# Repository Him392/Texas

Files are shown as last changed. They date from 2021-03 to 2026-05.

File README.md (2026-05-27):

# 德克萨斯 源石剑 自制道具

明日方舟「德克萨斯」源石剑的自制道具，包含 3D 打印手柄、亚克力剑身以及 ESP32 LED 控制固件。

Web BLE控制->https://him392.github.io/Texas/

视频链接：https://www.bilibili.com/video/BV1i34y1r77z

## 3D 预览

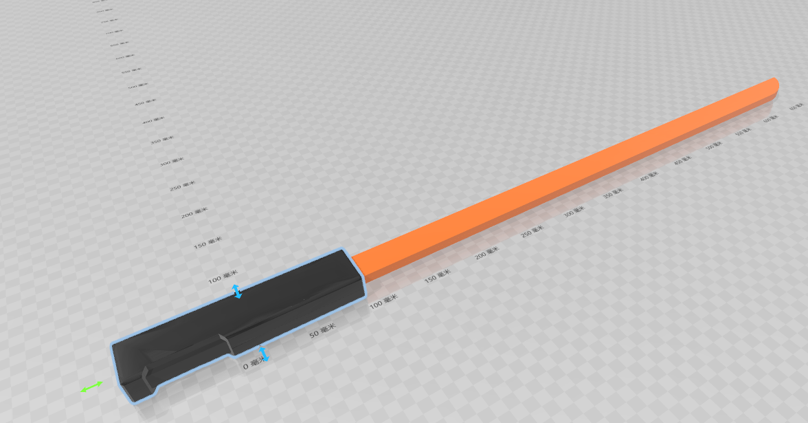
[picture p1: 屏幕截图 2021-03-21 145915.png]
预览图


## 文件说明

### 手柄部分（3D 打印）
| 文件 | 说明 |
|---|---|
| `Texas_1PCB.STL` / `.SLDPRT` | 手柄主体（装PCB的那面） |
| `Texas_2SW.STL` / `.SLDPRT` | 手柄主体（装开关的那面 |

### 剑身部分
| 文件 | 说明 |
|---|---|
| `Texas_A＆B_V2.DWG` | CAD 文件，用于淘宝定制亚克力板 |
| `Texas_A＆B_V2.SLDPRT` | SolidWorks 原始模型 |

### PCB
| 文件 | 说明 |
|---|---|
| `PCB(LCEDA).zip` | 立创 EDA PCB 工程文件 |

---

## 固件

固件基于 **ESP32-PICO** 平台（PlatformIO + Arduino 框架），LED 通过 LEDC PWM 驱动，提供两个版本：

### ESP32_AP — WiFi 热点控制版

- ESP32 开机后创建名为 **德克萨斯的源石剑-B** 的开放热点
- 手机/电脑连接热点后，访问 `192.168.4.1` 即可打开控制页面
- 控制功能：
  - **模式**：关闭 / 常亮 / 呼吸灯 / 闪烁
  - **亮度**调节滑块（常亮 / 闪烁模式下有效）
  - **实体按键**启用 / 禁用
  - 实时显示电池电压与 USB 充电状态
- 实体按键逻辑：
  - **短按**：关闭 ↔ 常亮 切换
  - **长按（250 ms）**：常亮 ↔ 呼吸灯 切换

### ESP32_BLE — 蓝牙 BLE 控制版

- 蓝牙广播名称：**Texas-Sword-B**
- 通过 BLE 特征值读写控制，断连后自动重新广播
- 支持通知推送：按键操作、USB 状态、电池电压实时同步给已连接设备
- BLE Service UUID：`4fafc201-1fb5-459e-8fcc-c5c9c331914b`
- 控制特征值：

| 功能 | UUID |
|---|---|
| 模式 | `beb5483e-36e1-4688-b7f5-ea07361b26a8` |
| 亮度 | `8c3bcf52-4752-46ac-a4de-a89e830e2f5f` |
| 实体按键 | `f0a3cc1e-eeed-426c-9a4f-ee72f778c1ee` |
| 电池电压 | `1de83dc6-3474-45e0-a2ef-cf4c01dcdc8c` |
| USB 状态 | `6bdab28d-19cd-488f-a42e-be255dfda983` |

### 引脚定义（两版通用）

| 信号 | GPIO |
|---|---|
| LED PWM | 12 |
| 实体按键 | 2 |
| USB 电源检测 | 36 |
| 电池电压 ADC | 37 |

---

## 开源协议

<br />
本项目采用 [CC BY-NC-SA 4.0](http://creativecommons.org/licenses/by-nc-sa/4.0/) 授权。

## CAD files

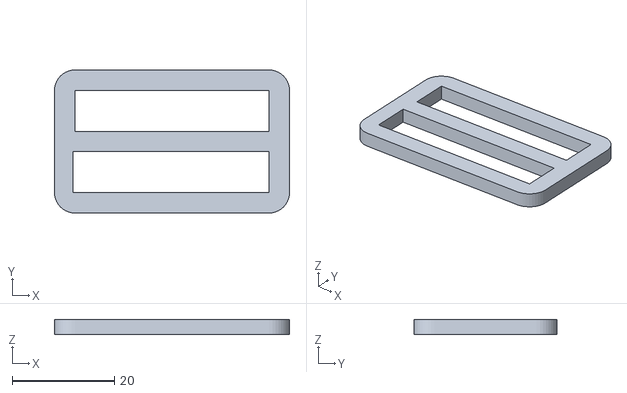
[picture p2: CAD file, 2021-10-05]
OLDFILES/日字扣（需100%填充打印）.STL
46.0 x 28.0 x 3.00

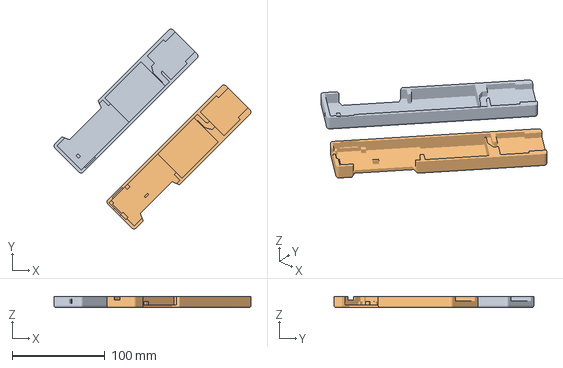
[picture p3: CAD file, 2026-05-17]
For Bambu Studio.3mf
212.3 x 215.4 x 12.0 mm
Texas_2SW.STL
Texas_1PCB.STL

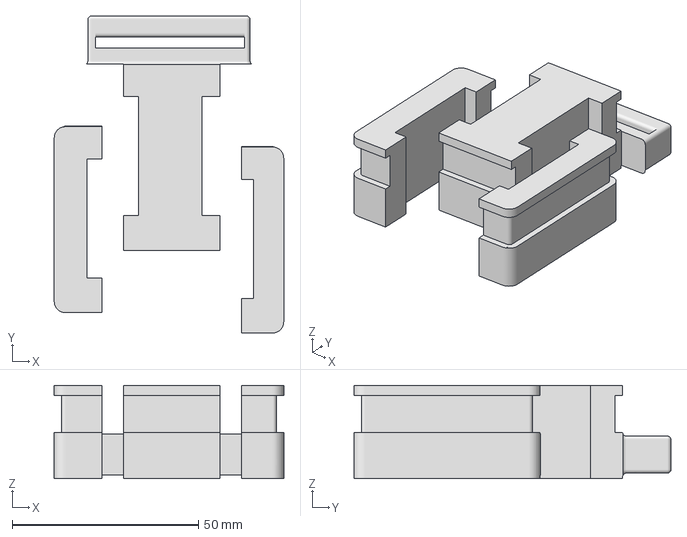
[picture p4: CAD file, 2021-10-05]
OLDFILES/刀架_拆件.3mf
61.7 x 85.2 x 25.0 mm

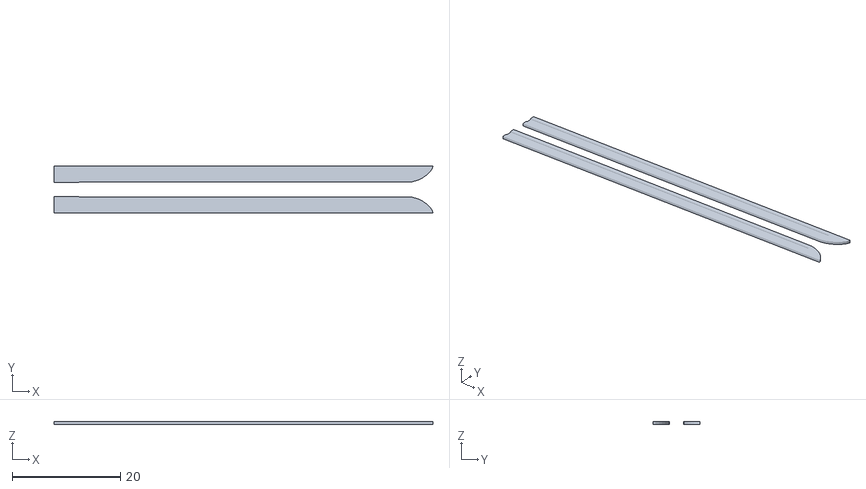
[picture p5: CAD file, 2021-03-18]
OLDFILES/Texas_A＆B.STL
70.0 x 8.67 x 0.505

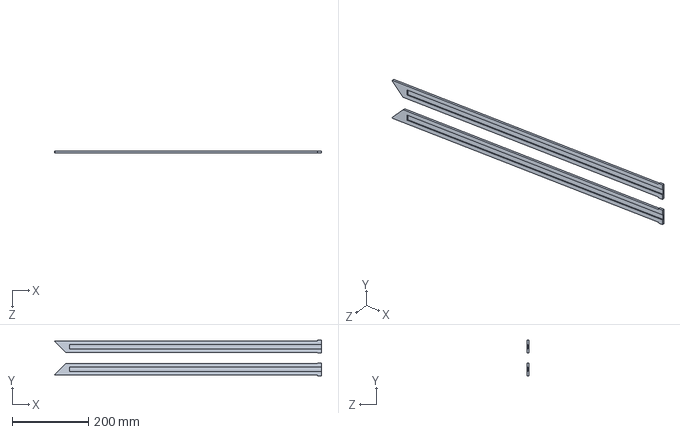
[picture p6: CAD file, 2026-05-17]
Texas_A＆B_V2.SLDPRT
698.3 x 93.2 x 5.00 mm

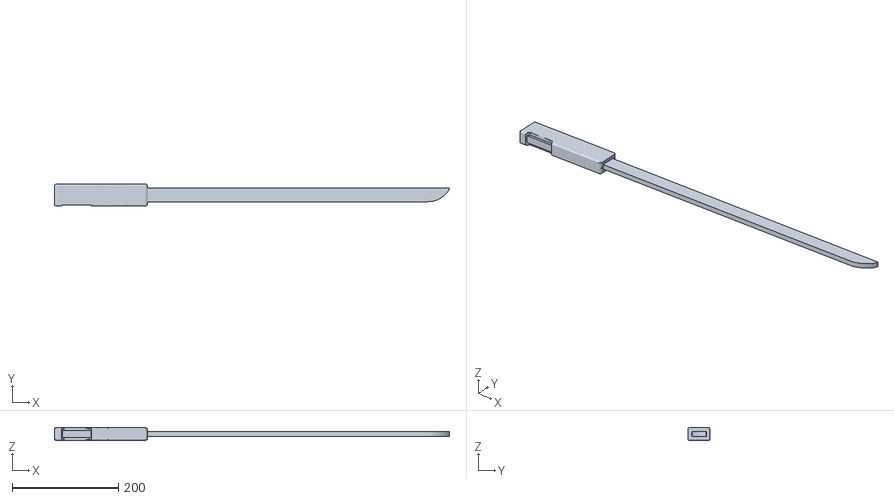
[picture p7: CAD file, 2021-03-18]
OLDFILES/Texas_ALL.stl
744.3 x 42.2 x 24.7

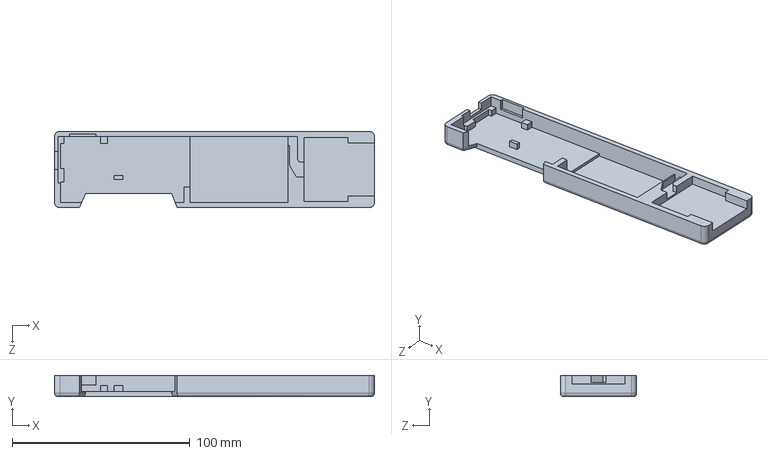
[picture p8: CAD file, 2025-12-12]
Texas_1PCB.SLDPRT
180.0 x 12.0 x 43.0 mm

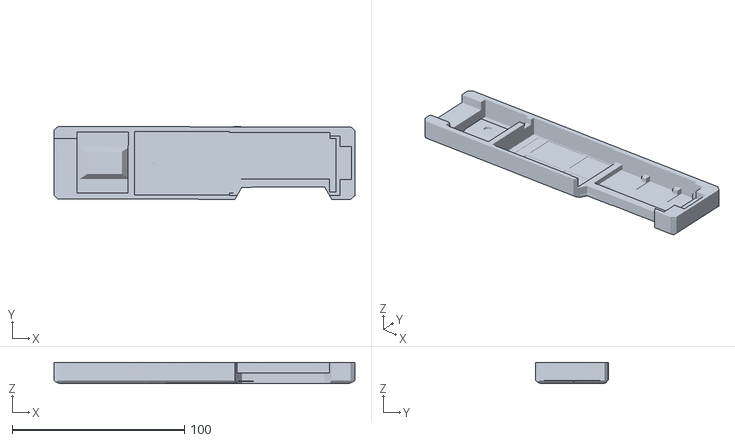
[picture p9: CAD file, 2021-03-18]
OLDFILES/Texas2.stl
174.9 x 42.2 x 12.3

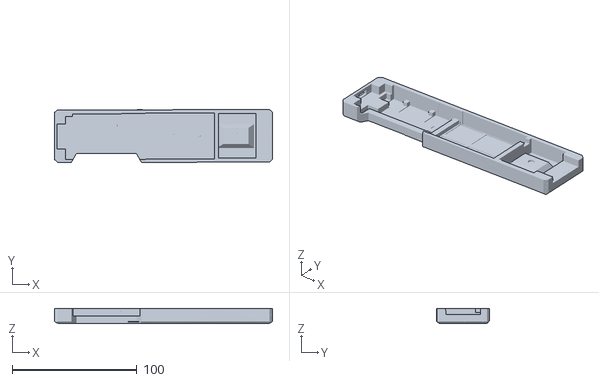
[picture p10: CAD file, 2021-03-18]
OLDFILES/Texas1.stl
174.9 x 42.2 x 12.3

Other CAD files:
Texas_A＆B_V2_带标注.DWG
Texas_2SW.SLDPRT
OLDFILES/Texas_A＆B.DWG
Texas_1PCB.STL
Texas_2SW.STL
Texas_A＆B_V2.DWG

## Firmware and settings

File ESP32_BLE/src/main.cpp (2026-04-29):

#include <Arduino.h>
#include <BLEDevice.h>
#include <BLEServer.h>
#include <BLEUtils.h>
#include <BLE2902.h>

// 全局参数
#define BLE_DEVICE_NAME    "Texas-Sword-B" // 蓝牙广播名称
#define LEDC_CHANNEL_0     0
#define LEDC_TIMER_8_BIT   12
#define LEDC_BASE_FREQ     8191//只给了14bit
#define LED_PIN            12
#define Debug              1   // 1开启打印日志和超控，0关闭
#define SAMPLE_COUNT       10  // 采样次数
#define Hardware_Fix       1  //修复新PCB占空比必须给到60才亮的问题

portMUX_TYPE mux = portMUX_INITIALIZER_UNLOCKED; // 定义一个多核锁

// 引脚定义
unsigned int SwitchPin = 2, USBPowerPin = 36, BATPin = 37;

// 全局变量
bool USBPowerState = false, KeyAvailable = true;
unsigned int Mode = 0, Temp_mode = 0;
unsigned long lastLogTime = 0;
int USBpower = 0;
float BATvotage = 0;
int brightness = 178;
int fadeAmount = 1;

// BLE Variables
BLEServer* pServer = NULL;
BLECharacteristic* pModeCharacteristic = NULL;
BLECharacteristic* pBrightnessCharacteristic = NULL;
BLECharacteristic* pKeyCharacteristic = NULL;
BLECharacteristic* pBatteryCharacteristic = NULL;
BLECharacteristic* pUsbCharacteristic = NULL;

bool deviceConnected = false;
bool oldDeviceConnected = false;

#define SERVICE_UUID           "4fafc201-1fb5-459e-8fcc-c5c9c331914b"
#define MODE_CHAR_UUID         "beb5483e-36e1-4688-b7f5-ea07361b26a8"
#define BRIGHTNESS_CHAR_UUID   "8c3bcf52-4752-46ac-a4de-a89e830e2f5f"
#define KEY_CHAR_UUID          "f0a3cc1e-eeed-426c-9a4f-ee72f778c1ee"
#define BATTERY_CHAR_UUID      "1de83dc6-3474-45e0-a2ef-cf4c01dcdc8c"
#define USB_CHAR_UUID          "6bdab28d-19cd-488f-a42e-be255dfda983"

class MyServerCallbacks : public BLEServerCallbacks {
    void onConnect(BLEServer* pServer) {
        deviceConnected = true;
    };

    void onDisconnect(BLEServer* pServer) {
        deviceConnected = false;
    }
};

class ModeCallbacks : public BLECharacteristicCallbacks {
    void onWrite(BLECharacteristic *pCharacteristic) {
        std::string value = pCharacteristic->getValue();
        if (value.length() > 0) {
            Mode = value[0];
            if (Mode == 2) brightness = 0; // 重置呼吸灯亮度
            Serial.printf("BLE 设置模式: %d\n", Mode);
        }
    }
};

class BrightnessCallbacks : public BLECharacteristicCallbacks {
    void onWrite(BLECharacteristic *pCharacteristic) {
        std::string value = pCharacteristic->getValue();
        if (value.length() > 0) {
            brightness = value[0];
            Serial.printf("BLE 设置亮度: %d\n", brightness);
        }
    }
};

class KeyCallbacks : public BLECharacteristicCallbacks {
    void onWrite(BLECharacteristic *pCharacteristic) {
        std::string value = pCharacteristic->getValue();
        if (value.length() > 0) {
            KeyAvailable = value[0];
            Serial.printf("BLE 实体按键状态: %s\n", KeyAvailable ? "启用" : "禁用");
        }
    }
};

// LED PWM 控制
void ledcAnalogWrite(uint8_t channel, uint32_t value, uint32_t valueMax = 255) {
  if (value == 0) {
    ledcWrite(channel, 0);
    return;
  }
  uint32_t duty = map(value, 0, valueMax, 0, 4095);
  duty = pow((float)duty / 4095.0, 2.2) * 4095;
  if (Hardware_Fix == 1) {
    duty = map(duty, 0, 4095, 2660, 4095); // 映射到65%~100%区间
  }
  ledcWrite(channel, duty);
}

// 按键中断处理函数
volatile bool isLongPress = false;
volatile bool buttonHeld = false;
hw_timer_t *pressTimer = NULL;

#define LONG_PRESS_TIME 250 // 250ms

void IRAM_ATTR handleLongPress() {
  if (KeyAvailable == false) return;
  if (buttonHeld) {
    isLongPress = true;
    if (Mode >= 1 && Mode <= 2) {
      Mode = (Mode % 2) + 1;
    }
  }
}

void IRAM_ATTR handleButtonPress() {
  if (KeyAvailable == false) return;
  static unsigned long pressStartTime = 0;
  unsigned long currentTime = millis();

  if (!buttonHeld) {  
    buttonHeld = true;
    isLongPress = false;
    pressStartTime = currentTime;
    timerAlarmWrite(pressTimer, LONG_PRESS_TIME * 1000, false);
    timerRestart(pressTimer);
    timerAlarmEnable(pressTimer);
  } else {  
    unsigned long pressDuration = currentTime - pressStartTime;
    buttonHeld = false;
    timerAlarmDisable(pressTimer);

    if (!isLongPress) {
      if (Mode != 0) {
        Mode = 0;  
      } else if (Mode == 0) {
        Mode = 1;  
      }
    }
  }
  
  // 更新BLE特征值
  if (pModeCharacteristic) {
      uint8_t m = Mode;
      pModeCharacteristic->setValue(&m, 1);
      pModeCharacteristic->notify();
  }
}

float readBatteryVoltage() {
  long sum = 0;
  for(int i = 0; i < SAMPLE_COUNT; i++){
    sum += analogRead(BATPin);
    delayMicroseconds(200);
  }
  float voltage = (sum / SAMPLE_COUNT) * 3.3f / 4095.0f * 2.0f;
  return voltage;
}

void setup() {
  pressTimer = timerBegin(1, 80, true);
  timerAttachInterrupt(pressTimer, &handleLongPress, true);

  Serial.begin(115200);
  Serial.println();
  Serial.println("初始化...");

  pinMode(SwitchPin, INPUT);
  attachInterrupt(digitalPinToInterrupt(SwitchPin), handleButtonPress, CHANGE);

  // 初始化蓝牙
  BLEDevice::init(BLE_DEVICE_NAME);
  pServer = BLEDevice::createServer();
  pServer->setCallbacks(new MyServerCallbacks());

  BLEService *pService = pServer->createService(SERVICE_UUID);

  pModeCharacteristic = pService->createCharacteristic(
                      MODE_CHAR_UUID,
                      BLECharacteristic::PROPERTY_READ   |
                      BLECharacteristic::PROPERTY_WRITE  |
                      BLECharacteristic::PROPERTY_WRITE_NR |
                      BLECharacteristic::PROPERTY_NOTIFY
                    );
  pModeCharacteristic->addDescriptor(new BLE2902());
  pModeCharacteristic->setCallbacks(new ModeCallbacks());
  uint8_t initialMode = Mode;
  pModeCharacteristic->setValue(&initialMode, 1);

  pBrightnessCharacteristic = pService->createCharacteristic(
                      BRIGHTNESS_CHAR_UUID,
                      BLECharacteristic::PROPERTY_READ   |
                      BLECharacteristic::PROPERTY_WRITE  |
                      BLECharacteristic::PROPERTY_WRITE_NR
                    );
  pBrightnessCharacteristic->setCallbacks(new BrightnessCallbacks());
  uint8_t initialBr = brightness;
  pBrightnessCharacteristic->setValue(&initialBr, 1);

  pKeyCharacteristic = pService->createCharacteristic(
                      KEY_CHAR_UUID,
                      BLECharacteristic::PROPERTY_READ   |
                      BLECharacteristic::PROPERTY_WRITE  |
                      BLECharacteristic::PROPERTY_WRITE_NR |
                      BLECharacteristic::PROPERTY_NOTIFY
                    );
  pKeyCharacteristic->addDescriptor(new BLE2902());
  pKeyCharacteristic->setCallbacks(new KeyCallbacks());
  uint8_t initialKey = KeyAvailable;
  pKeyCharacteristic->setValue(&initialKey, 1);

  pBatteryCharacteristic = pService->createCharacteristic(
                      BATTERY_CHAR_UUID,
                      BLECharacteristic::PROPERTY_READ   |
                      BLECharacteristic::PROPERTY_NOTIFY
                    );
  pBatteryCharacteristic->addDescriptor(new BLE2902());

  pUsbCharacteristic = pService->createCharacteristic(
                      USB_CHAR_UUID,
                      BLECharacteristic::PROPERTY_READ   |
                      BLECharacteristic::PROPERTY_NOTIFY
                    );
  pUsbCharacteristic->addDescriptor(new BLE2902());

  pService->start();

  BLEAdvertising *pAdvertising = BLEDevice::getAdvertising();
  pAdvertising->addServiceUUID(SERVICE_UUID);
  pAdvertising->setScanResponse(true);
  pAdvertising->setMinPreferred(0x06);
  pAdvertising->setMinPreferred(0x12);
  BLEDevice::startAdvertising();

  pinMode(LED_PIN, INPUT_PULLUP);
  delay(100);
  pinMode(LED_PIN, OUTPUT);

  ledcSetup(LEDC_CHANNEL_0, LEDC_BASE_FREQ, LEDC_TIMER_8_BIT);
  ledcAttachPin(LED_PIN, LEDC_CHANNEL_0);
  
  Serial.println("BLE 已经开启并开始广播.");
}

void loop() {
  if (millis() - lastLogTime >= 500) { 
    lastLogTime = millis();

    USBpower = analogRead(USBPowerPin);
    USBPowerState = (USBpower > 2500);
    BATvotage = readBatteryVoltage();

    if (Debug) {
      Serial.printf(
        "模式:%d | 亮度:%d | 电压:%.2fV | USB:%s\n",
        Mode, brightness, BATvotage,
        USBPowerState ? "插入" : "拔出"
      );
    }
    
    // 如果蓝牙连接，通知状态更新
    if (deviceConnected) {
        uint8_t usb = USBPowerState ? 1 : 0;
        pUsbCharacteristic->setValue(&usb, 1);
        pUsbCharacteristic->notify();
        
        pBatteryCharacteristic->setValue(BATvotage);
        pBatteryCharacteristic->notify();
    }
  }

  // 处理蓝牙重连广告
  if (!deviceConnected && oldDeviceConnected) {
      delay(500); // 留出时间给蓝牙栈准备
      pServer->startAdvertising(); // 重新广播
      Serial.println("重连: 开始广播");
      oldDeviceConnected = deviceConnected;
  }
  if (deviceConnected && !oldDeviceConnected) {
      oldDeviceConnected = deviceConnected;
  }

  if (USBPowerState && !Debug) {
    Mode=0;
    if (pModeCharacteristic) {
        uint8_t m = Mode;
        pModeCharacteristic->setValue(&m, 1);
        pModeCharacteristic->notify();
    }
  }

  switch (Mode) {
    case 0:
      ledcAnalogWrite(LEDC_CHANNEL_0, 0);
      break;
    case 1:
      ledcAnalogWrite(LEDC_CHANNEL_0, brightness);
      break;
    case 2:
      brightness += fadeAmount;
      if (brightness <= 0 || brightness >= 254) fadeAmount = -fadeAmount;
      ledcAnalogWrite(LEDC_CHANNEL_0, brightness);
      delay(10);
      break;
    case 3:
      ledcAnalogWrite(LEDC_CHANNEL_0, brightness);
      delay(50);
      ledcAnalogWrite(LEDC_CHANNEL_0, 0);
      delay(50);
      break;
  }
}

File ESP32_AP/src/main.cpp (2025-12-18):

#include <Arduino.h> 
#include <WiFi.h>
#include <esp_wifi.h>
#include <ESPAsyncWebServer.h>
//全局参数
#define LEDC_CHANNEL_0     0
#define LEDC_TIMER_8_BIT   12
#define LEDC_BASE_FREQ     8191//只给了14bit
#define LED_PIN            12
#define Debug            1  // 1开启打印日志和超控，0关闭
#define SAMPLE_COUNT       10  // 采样次数

portMUX_TYPE mux = portMUX_INITIALIZER_UNLOCKED; // 定义一个多核锁

const char* ssid     = "德克萨斯的源石剑-B";
const char* password = "";
// 引脚定义
unsigned int SwitchPin = 2, USBPowerPin = 36,BATPin=37;
// 全局变量
bool USBPowerState = false,KeyAvailable=true;
unsigned int Mode = 0, Temp_mode = 0;
unsigned long lastLogTime = 0;
int USBpower=0;
float BATvotage=0;
int brightness = 128;
int fadeAmount = 1;

AsyncWebServer server(80);

// LED PWM 控制
void ledcAnalogWrite(uint8_t channel, uint32_t value, uint32_t valueMax = 255) {
  uint32_t duty = map(value, 0, valueMax, 0, 4095);
  duty = pow((float)duty / 4095.0, 2.2) * 4095;
  duty = map(duty,0,4095,1000,4095);
  ledcWrite(channel, duty);
}

// 按键中断处理函数
volatile bool isLongPress = false;  // 记录是否已触发长按
volatile bool buttonHeld = false;   // 按键是否被按住
hw_timer_t *pressTimer = NULL;      // 定时器

#define LONG_PRESS_TIME 250 // 250ms 作为长按阈值

void IRAM_ATTR handleLongPress() {
  if (KeyAvailable==false) return;
  
  if (buttonHeld) {  // 只有按住时才触发
    isLongPress = true;
    if (Mode >= 1 && Mode <= 2) {
      Mode = (Mode % 2) + 1;  // 1 → 2  → 1 循环（闪烁为WEB ONLY）
    }
  }
}

void IRAM_ATTR handleButtonPress() {
  if (KeyAvailable==false) return;
  static unsigned long pressStartTime = 0;
  unsigned long currentTime = millis();

  if (!buttonHeld) {  
    buttonHeld = true;
    isLongPress = false; // 重置长按状态
    pressStartTime = currentTime;
    timerAlarmWrite(pressTimer, LONG_PRESS_TIME * 1000, false); // 250ms 后触发
    timerRestart(pressTimer);
    timerAlarmEnable(pressTimer);
  } else {  
    unsigned long pressDuration = currentTime - pressStartTime;
    buttonHeld = false;
    timerAlarmDisable(pressTimer); // 释放按键后禁用定时器

    if (!isLongPress) {  // 如果长按已经触发，就不执行短按逻辑
      if (Mode != 0) {
        Mode = 0;  
      } else if (Mode == 0) {
        Mode = 1;  
      }
    }
  }
}
// ------- 电池电压采样函数（带滤波） -------
float readBatteryVoltage() {
  long sum = 0;
  for(int i = 0; i < SAMPLE_COUNT; i++){
    sum += analogRead(BATPin);
    delayMicroseconds(200); // 小延时让 ADC 更稳定
  }

  float voltage = (sum / SAMPLE_COUNT) * 3.3f / 4095.0f * 2.0f;
  return voltage;
}

void setup() {
  pressTimer = timerBegin(1, 80, true);
  timerAttachInterrupt(pressTimer, &handleLongPress, true);

  Serial.begin(115200);
  Serial.println();
  Serial.println("正在配置热点...");

  pinMode(SwitchPin, INPUT);
  attachInterrupt(digitalPinToInterrupt(SwitchPin), handleButtonPress, CHANGE);

  WiFi.softAP(ssid, password);
  IPAddress myIP = WiFi.softAPIP();
  esp_wifi_set_max_tx_power(WIFI_POWER_11dBm);
  Serial.print("AP IP地址: ");
  Serial.println(myIP);

server.on("/", HTTP_GET, [](AsyncWebServerRequest *request) {
String html = R"rawliteral(
<!DOCTYPE html>
<html>
<head>
<meta charset="UTF-8">
<meta name="viewport" content="width=device-width, initial-scale=1">
<title>ESP32 LED 控制</title>
<style>
body {
  font-family: Arial, sans-serif;
  margin: 0; padding: 20px;
  background: #f2f2f2;
}

h1 { font-size: 26px; margin-bottom: 15px; }

button {
  font-size: 18px; padding: 10px 14px;
  margin: 6px; border: none;
  border-radius: 6px; cursor: pointer;
  background: #2196F3; color: white;
}
button:active { background: #0b7dda; }

input[type="range"] {
  width: 100%;
  margin-top: 5px;
}

.status-box {
  background: white;
  padding: 12px;
  border-radius: 10px;
  box-shadow: 0 2px 5px rgba(0,0,0,0.15);
  margin-bottom: 20px;
  line-height: 1.6;
  font-size: 18px;
}
</style>
</head>
<body>

<h1>ESP32 LED 控制</h1>

<div class="status-box">
<p>模式: <strong><span id="currentMode">--</span></strong></p>
<p>电池电压: <strong><span id="batteryVoltage">--</span> V</strong></p>
<p>USB状态: <strong><span id="usbState">--</span></strong></p>
<p>实体按键: <strong><span id="keyStatus">启用</span></strong></p>
</div>

<button onclick="setMode(0)">关闭</button>
<button onclick="setMode(1)">开启</button>
<button onclick="setMode(2)">呼吸</button>
<button onclick="setMode(3)">闪烁</button>

<p>亮度:</p>
<input type="range" min="0" max="255" value="128" id="brightnessRange"
       onchange="setBrightness(this.value)" disabled>

<hr>

<button onclick="toggleKey()" id="keyBtn">禁用实体按键</button>

<script>
function setMode(mode) {
  fetch('/setMode?value=' + mode);
  document.getElementById("currentMode").innerText = mode;

  document.getElementById("brightnessRange").disabled = !(mode === 1 || mode === 3);
}

function setBrightness(value) {
  fetch('/brightness?value=' + value);
}

function toggleKey() {
  fetch('/toggleKey')
    .then(response => response.text())
    .then(state => {
      if (state === "ENABLED") {
        document.getElementById("keyStatus").innerText = "启用";
        document.getElementById("keyBtn").innerText = "禁用实体按键";
      } else {
        document.getElementById("keyStatus").innerText = "禁用";
        document.getElementById("keyBtn").innerText = "启用实体按键";
      }
    });
}

// ---- 自动刷新状态，每秒从 /status 拉取 ----
setInterval(() => {
  fetch('/status')
    .then(response => response.json())
    .then(data => {
      document.getElementById("currentMode").innerText = data.mode;
      document.getElementById("batteryVoltage").innerText = data.battery.toFixed(2);
      document.getElementById("usbState").innerText = data.usb ? "插入" : "拔出";
    });
}, 1000);

</script>
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

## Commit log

2021-08-16 剑体V2，修复了塞不进去硬灯条的问题
    [Texas_A＆B_V2.SLDPRT, Texas_A＆B_V2.STL]
2021-08-16 V2的DWG文件貌似有点问题，建议用SW工程文件
    [Texas_A＆B_V2.DWG]
2022-04-07 CNC(测试)
    [Texas_A＆B_V2.STEP]
2022-04-07 Create Texas_AB_V2 - 副本.STEP
    [Texas_AB_V2 - 副本.STEP]
2023-09-24 整理文件
    [Texas_A＆B.DWG, Texas_A＆B.STL]
2023-09-24 充电控制二合一PCB 还没焊接测试 先别用
2024-02-05 按设定集微调外形、增加止动块
    [Texas_A＆B_V2.SLDPRT]
2024-12-06 ESP32控制板/开发中
2025-02-25 v0.9.99999，堂堂发布！
2025-02-27 V1.0正式版
2025-03-08 完成手柄模型重构，适配新ESP32 PCB
    [Texas1.SLDPRT, Texas1.STL, Texas2.SLDPRT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]
2025-04-07 屎山就屎山 懒得改了
    [Texas_1PCB.SLDPRT, Texas_1PCB.STL]
2025-08-28 change:调整触摸开关位置，防止使用过程中误触
    [Texas_1PCB.SLDPRT, Texas_1PCB.STL, Texas_2SW.SLDPRT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]
2025-12-03 new＆fix:修改前端UI，并支持禁用实体按键、添加电压显示、修复呼吸模式在最高亮度下的闪烁问题
    已测直接推到main
2025-12-03 change: 降低WIFI发射功率至11dBm
    哎我草没给天线做匹配，芯片发热真大吧
2025-12-12 fix：修复PCB上元件与打印件打架的问题
    [Texas_1PCB.SLDPRT, Texas_1PCB.STL]
2026-04-29 添加ble版本固件，使用webapp作上位机
2026-04-29 删除临时文件
2026-04-29 Add GitHub Pages deployment workflow for ESP32_BLE webapp
    Agent-Logs-Url: https://github.com/Him392/Texas/sessions/b10f2234-7584-48a7-9b1b-ab17cc480ddd
2026-04-29 docs: 更新 README，补充固件说明与当前文件列表
    Agent-Logs-Url: https://github.com/Him392/Texas/sessions/2c0a021b-4a73-4b24-a680-127da2a1bcf5
2026-04-30 更新 README.md
2026-05-17 更新文件
    [For Bambu Studio.3mf, Texas_A＆B_V2.SLDPRT, Texas_A＆B_V2_带标注.DWG]
